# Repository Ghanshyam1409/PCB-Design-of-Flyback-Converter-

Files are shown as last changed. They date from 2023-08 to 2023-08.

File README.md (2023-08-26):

# PCB-Design-of-Closed- Loop-Flyback-Converter-
 PCB Design  of closed loop operation  Flyback Converter 
Flyback converter is DC-DC converter it is isolated converter we use transformer to boost the output voltage as compare to conventional DC-DC converter, Here we design the PCB for closed Loop opreation of Flyback Converter for controlling the output voltage of flyback converter we use type -II Compenstor topology

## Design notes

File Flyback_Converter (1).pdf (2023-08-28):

# Self Project

PCB Design of Clsoed Loop Control of Flyback Converter

Name : - GHANSHYAM DAS GUPTA Roll no . 224102109

## 1 Objective:

PCB Design of Flyback converter which is type of isolated converter, while we are using flyback converter as open loop configuration we will get the output voltage more than we required , so we use Type - II Compensator to regulate the output Voltage as per are requirement; Desired Gain Cross Over Frequency of Compensated System : 100Hz ; Desired Phase Margin : 120 degree

## 2 Given Parameter:

There are the parameter that we are going to use design of flyback converter

Input Voltage = 24 V , Duty Ratio= 0.33 , Capacitor = 220µF , Turn Ratio = 1 : 5 , Inductor = 22µH , Resistor = 5Ω , Inductor Resistance = 1Ω, D’=1 − 0.33 = 0.67,Switching Frequency = 10 KHz

## 3 Flyback Converter Design:

### 3.1 Derivation of Transfer function using small signal analysis:

The transfer function is derived using small signal analysis comes as:

Gvd(s) = Vo(s)
D(s)

=

Vin +

VO
n −

n∗VO
R∗D′ −

VO
R∗D′ ∗ (LS + D ∗ r)

n
D′ ∗

RCS+1
R

∗ (LS + D ∗ r) + D′
n

(1)

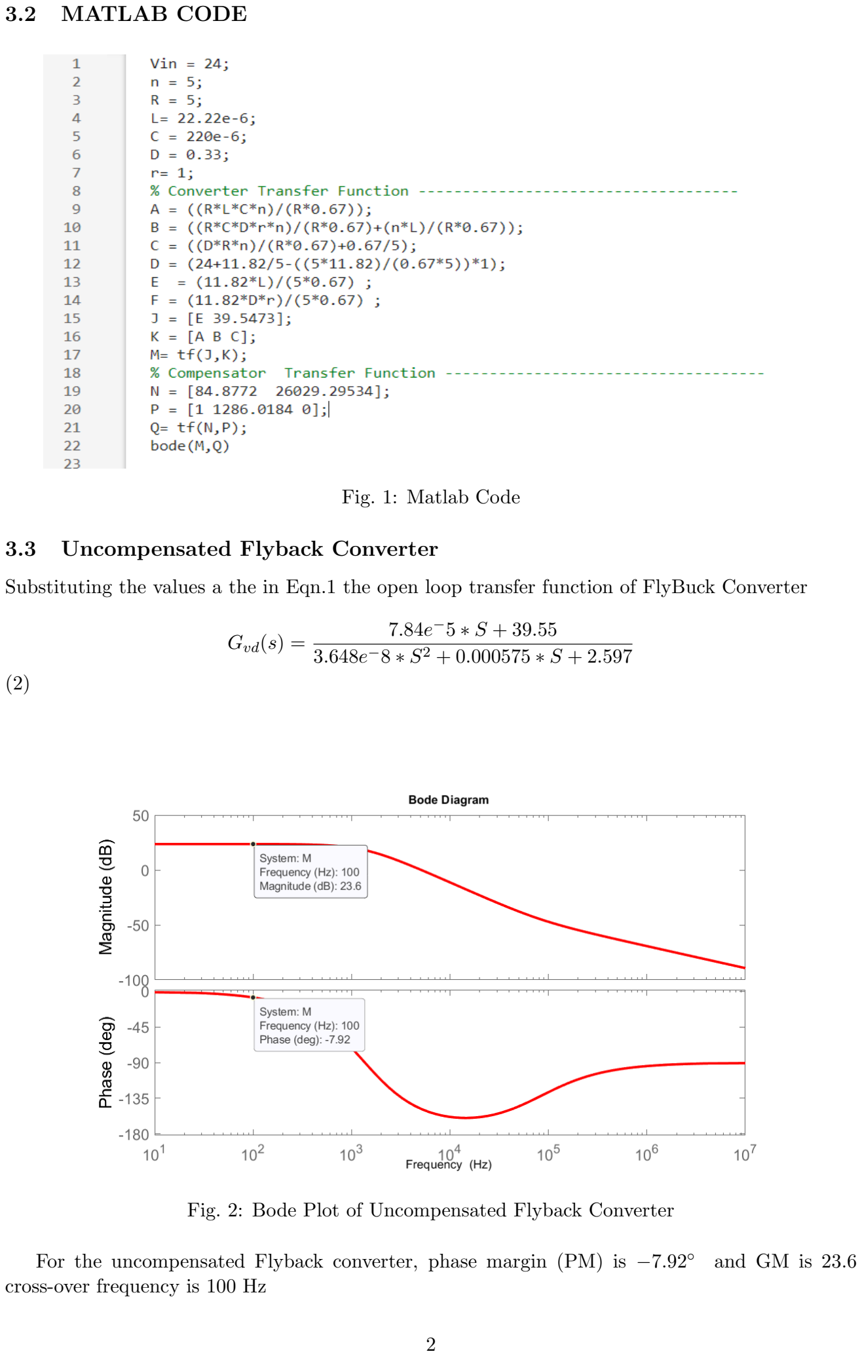
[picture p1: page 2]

### 3.2 MATLAB CODE

Fig. 1: Matlab Code

### 3.3 Uncompensated Flyback Converter

Substituting the values a the in Eqn.1 the open loop transfer function of FlyBuck Converter

Gvd(s) = | 7.84e

−5 ∗ S + 39.55
| 3.648e⁻8 ∗ S² + 0.000575 ∗ S + 2.597
(2)

Fig. 2: Bode Plot of Uncompensated Flyback Converter

For the uncompensated Flyback converter, phase margin (PM) is −7.92◦ and GM is 23.6 cross-over frequency is 100 Hz

### 3.4 Design of TYPE- II Compensator

- Since Desired the gain cross-over frequency 100 Hz. value of GMB is Given by

20 ∗ log 10K = 23.6

k = 15.1356

GMB =

1
K

= 0.0660

(3)

- Phase Margin (P.M.) is given 120◦
the phase margin of uncompensated Buck converter at Wgc is −7.94◦ by the help of this we can easily find the phase boost for that given system

ϕb = ϕm - ϕp -90◦
ϕb = 120◦ +0.907◦

-90◦
ϕb = 37.94◦

(4)

- Transfer Function of TYPE -II compensator is given by

a(s) = GMB ∗ (1 + ωz
s

)
(1 + s
ωp

)

(5)

k = tan(45◦ + ϕb/ 2)

k =1.732
ωz = (ωc)/k
ωp = (ωc)*k

On putting these two conditions, GMB = 0.0660 , ωz =306.670 rad/sec and ωp =1286.0184 rad/sec are obtained.

- The Transfer Function of TYPE- II Compensater is given by

a(s) = 84.8772 ∗ S + 26029.29534 S² + 1286.0184 ∗ S

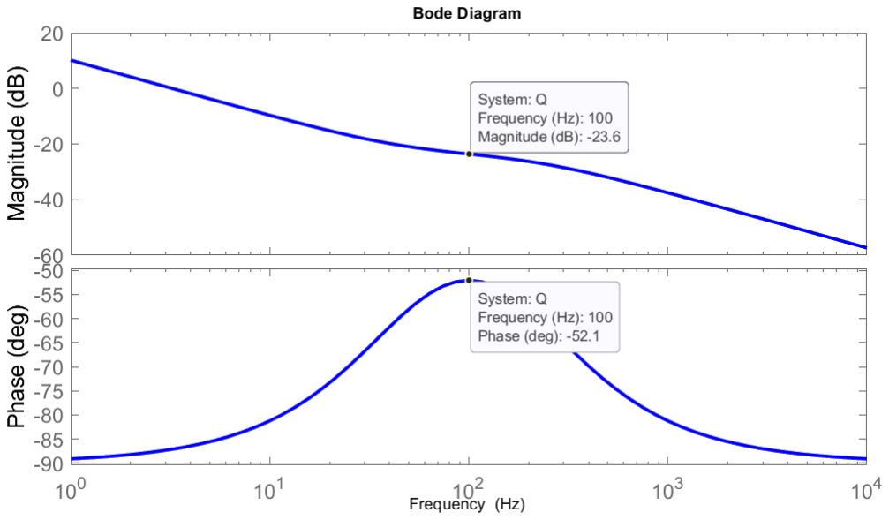
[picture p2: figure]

Fig. 3: Bode Plot of TYPE-II Compeansator

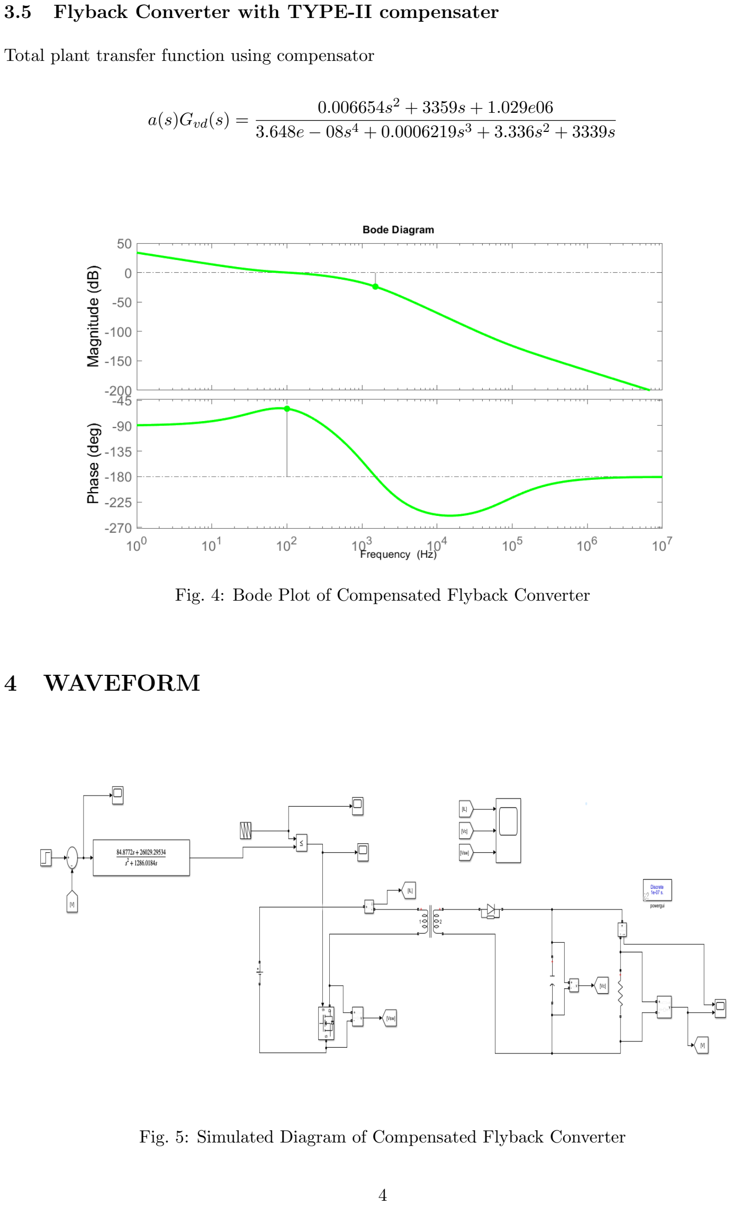
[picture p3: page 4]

### 3.5 Flyback Converter with TYPE-II compensater

Total plant transfer function using compensator

a(s)Gvd(s) = | 0.006654s

2 + 3359s + 1.029e06
| 3.648e − 08s 4 + 0.0006219s

3 + 3.336s

2 + 3339s

Fig. 4: Bode Plot of Compensated Flyback Converter

## 4 WAVEFORM

Fig. 5: Simulated Diagram of Compensated Flyback Converter

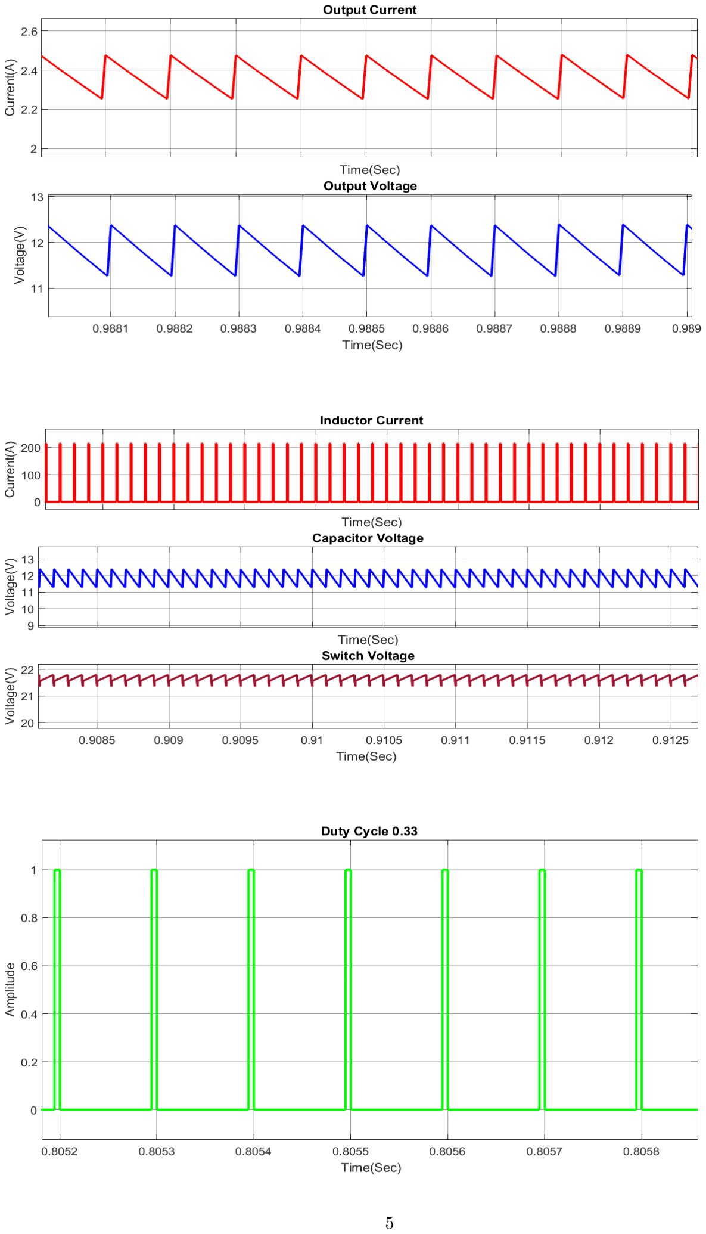
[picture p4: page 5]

## 5 LTspice Circuit Diagram

### 5.1 Triangular wave generator

Here we are generating triangular wave using op-amp and the switching frequency of MOSFET is 10 KHz whose peak to peak output voltage is 10 V , here we are considering resistance R1 =10Ω and capacitor c= 0.01µ F. Saturation voltage of op-amp is 15V

V (P − P) = 2 ∗

R2
R1

∗ Vsat

f =

R1
4 ∗ R3 ∗ R2 ∗ C1

### 5.2 Op-amp Subtractor

we design op-amp subs tractor to generate error and given it to the signal compansator then switching using gate driver. The output of the substractor must vary form 0 to 1, we take error value 0.5.so the calculted output value 11.82 and reference are given from the flyback output

Vo =

R2
R1

∗ (11.82 − Vout)

R1 = 0.0520K, R2 = 5.20K

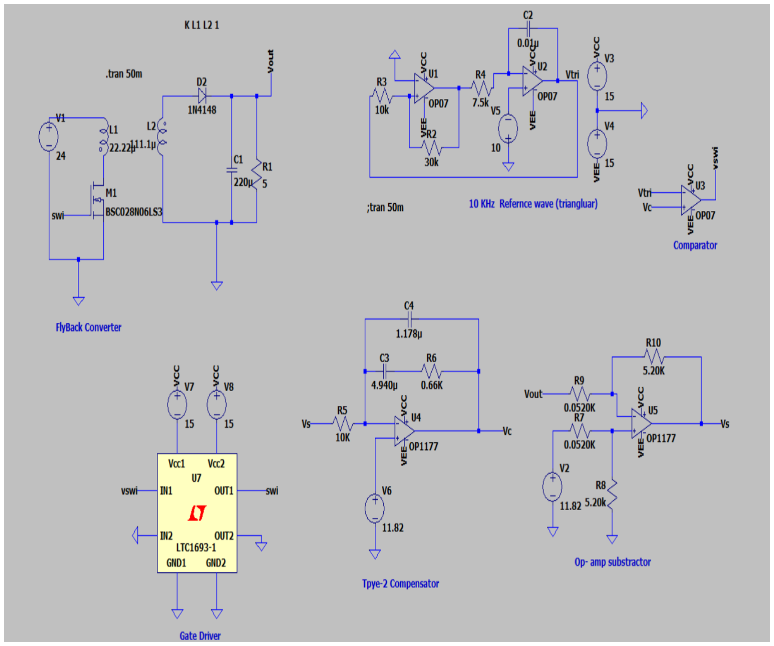
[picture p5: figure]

## 6 PCB module

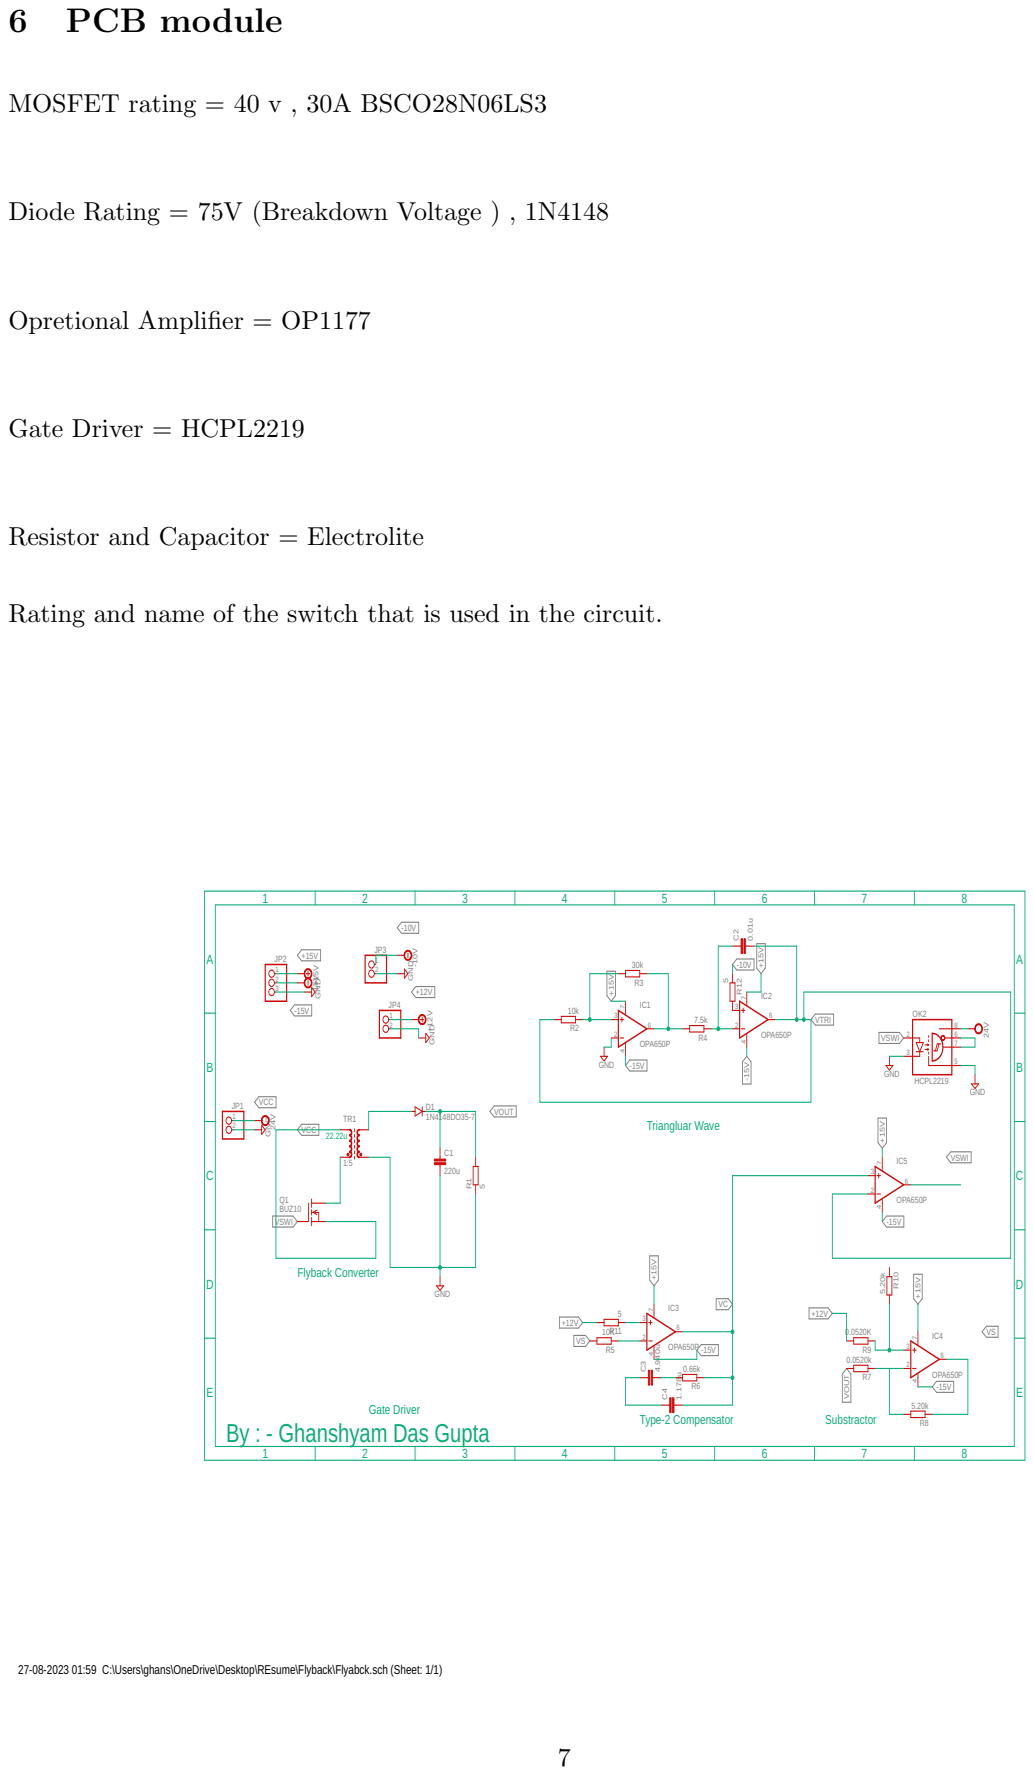
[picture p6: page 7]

Diode Rating = 75V (Breakdown Voltage ) , 1N4148

Resistor and Capacitor = Electrolite

Rating and name of the switch that is used in the circuit.

By : - Ghanshyam Das Gupta

27-08-2023 01:59 C:\Users\ghans\OneDrive\Desktop\REsume\Flyback\Flyabck.sch (Sheet: 1/1)

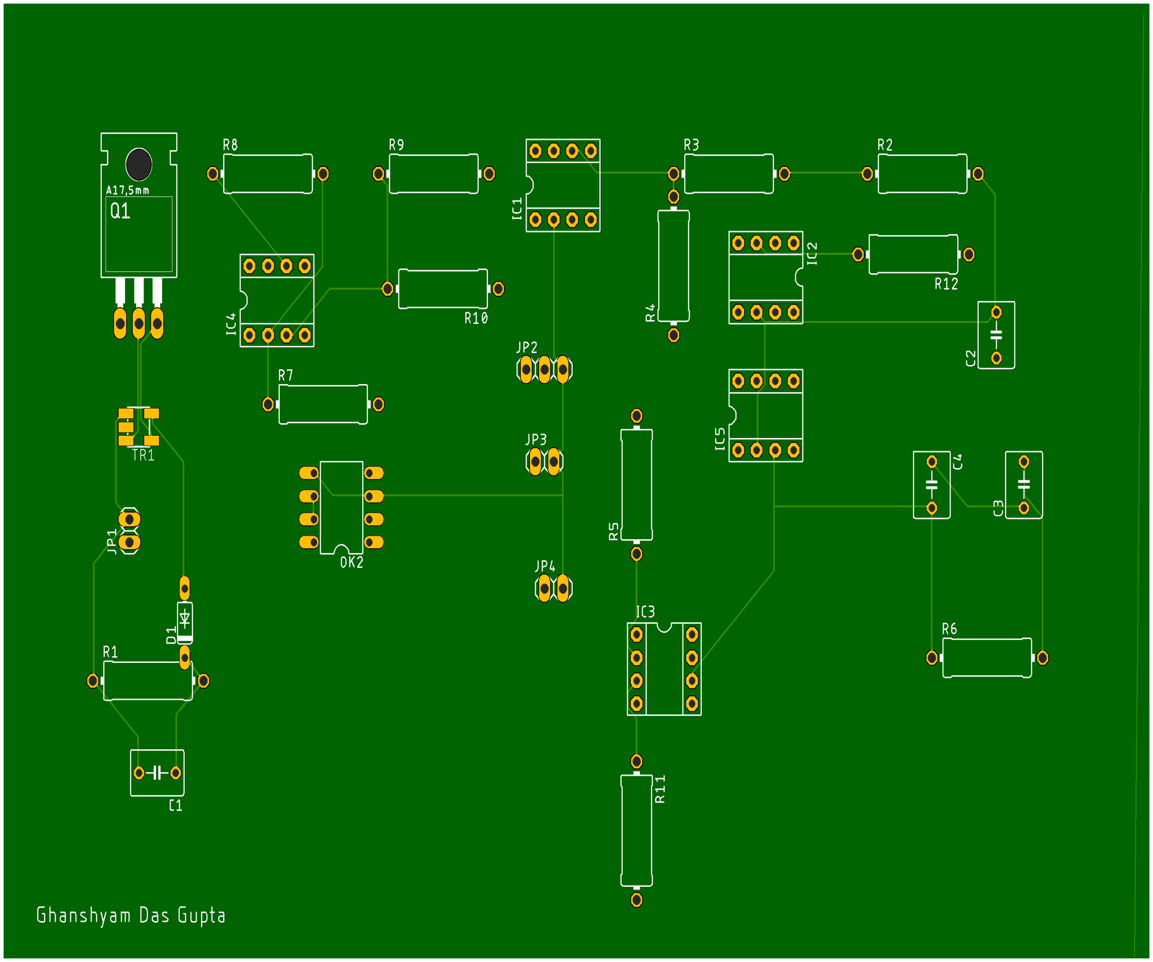
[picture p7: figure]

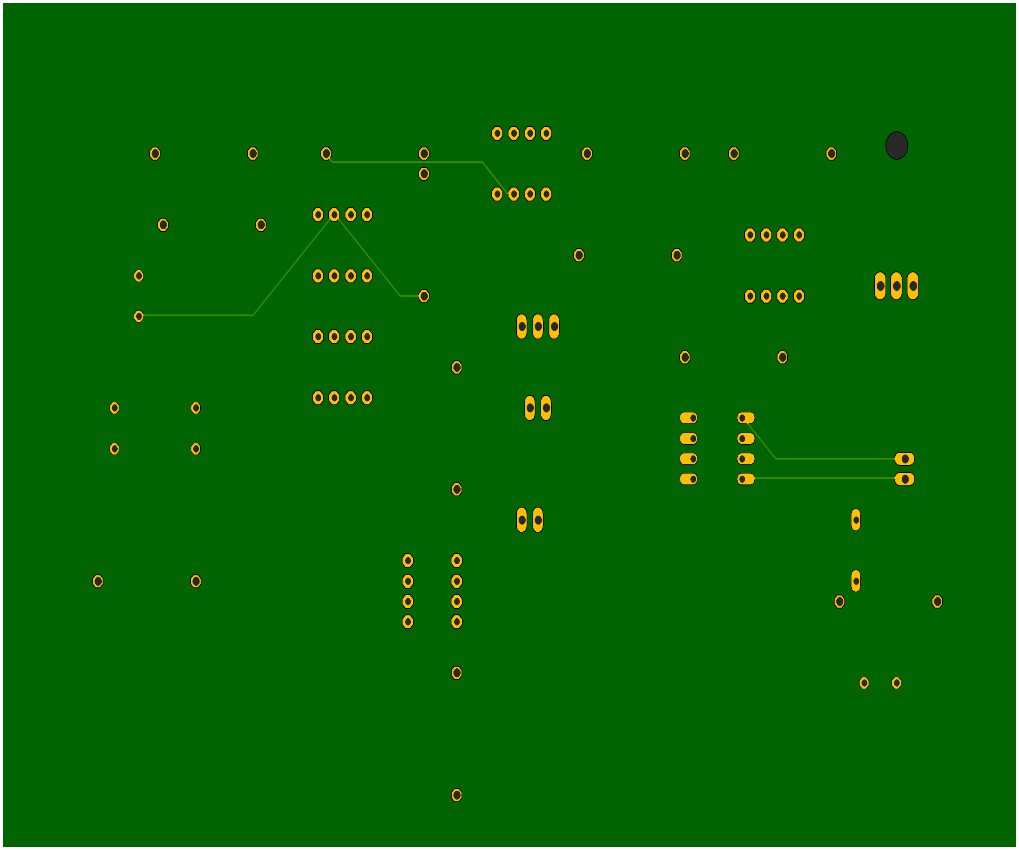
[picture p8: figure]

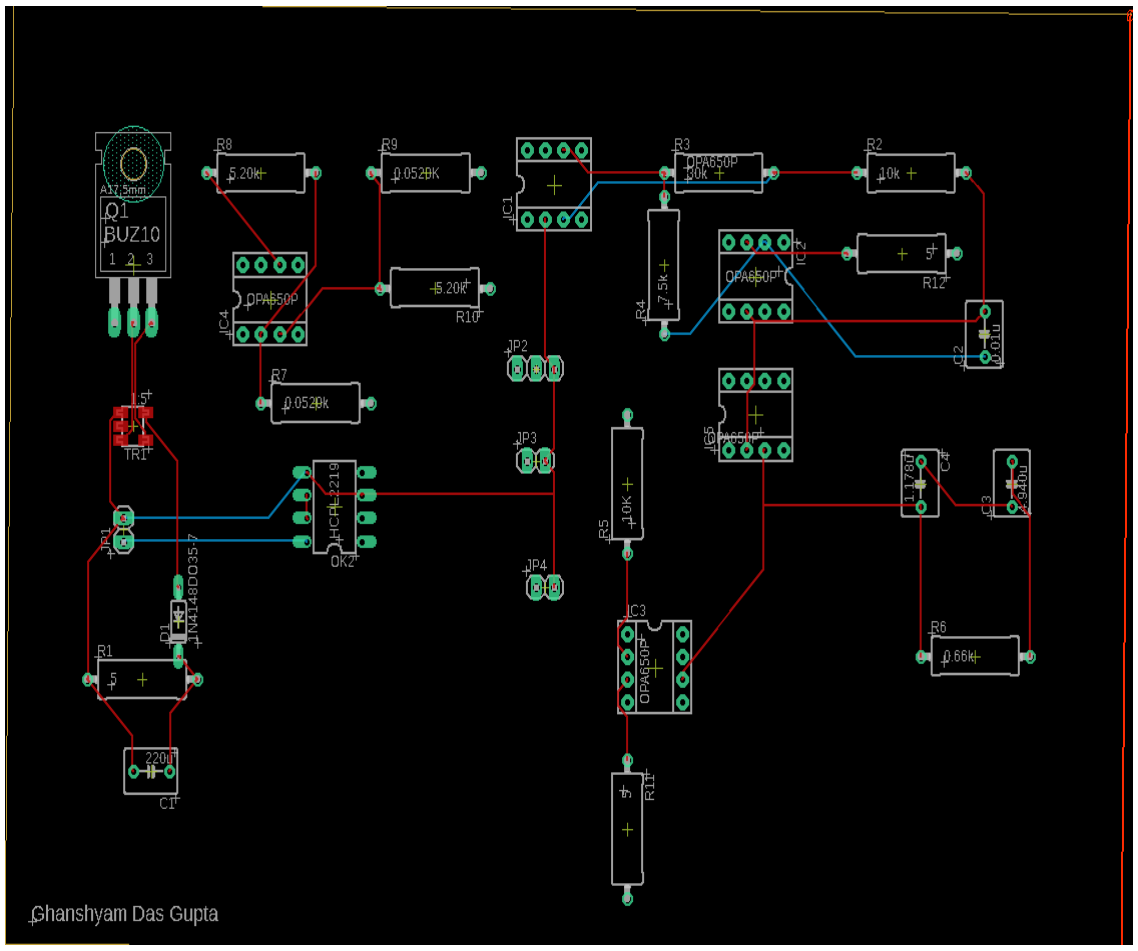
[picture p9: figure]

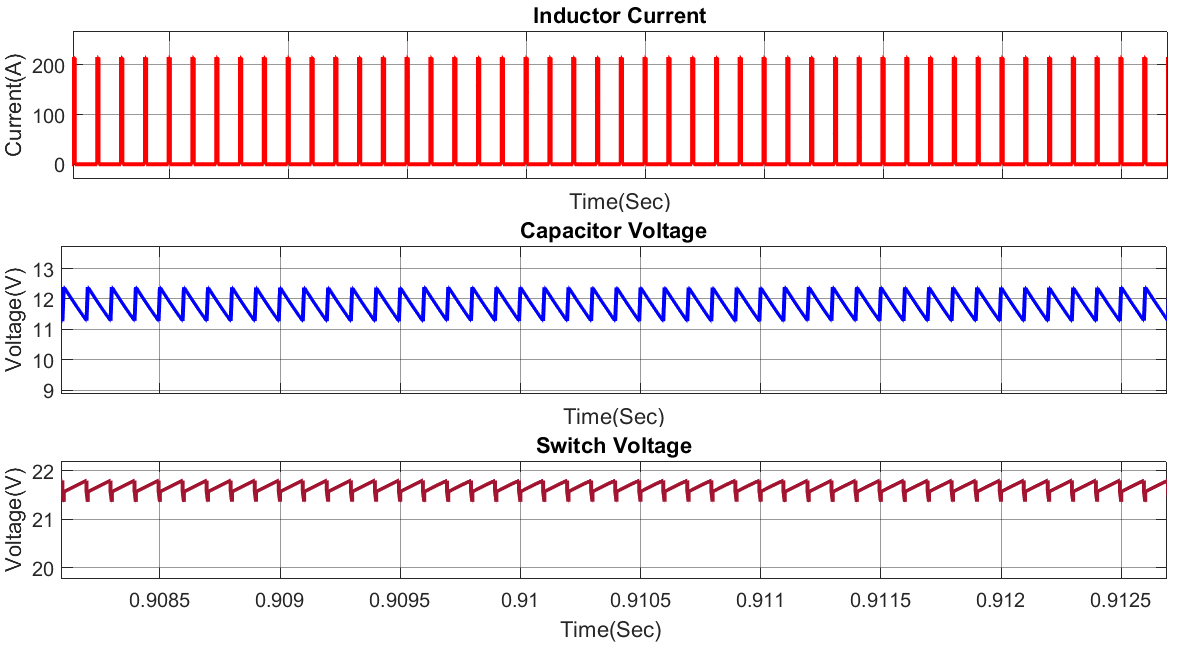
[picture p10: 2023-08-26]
swv.png

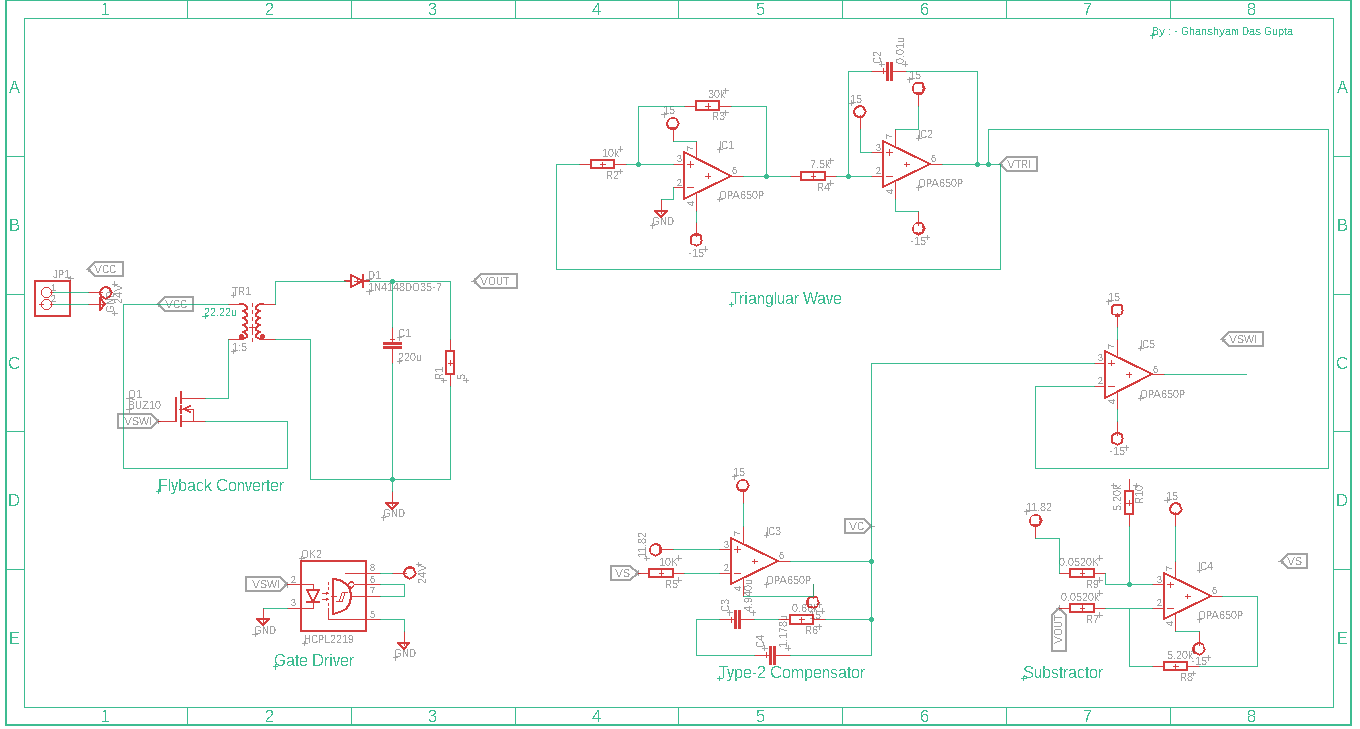
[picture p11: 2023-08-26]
pcb2.png

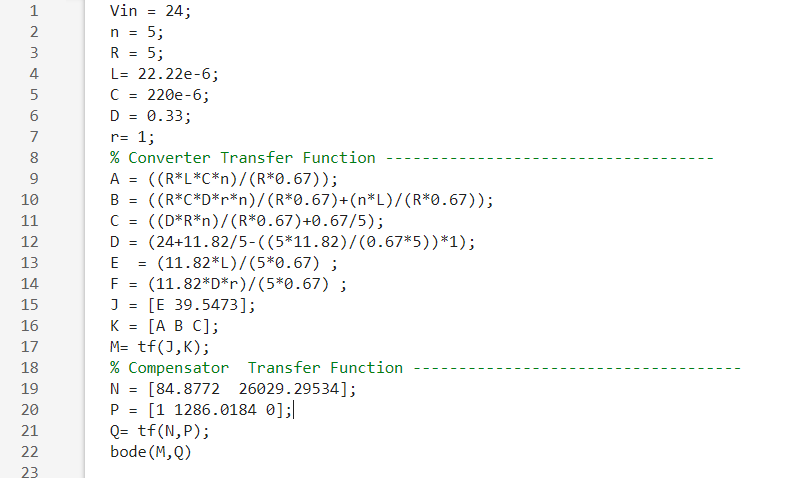
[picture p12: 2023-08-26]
tF.png

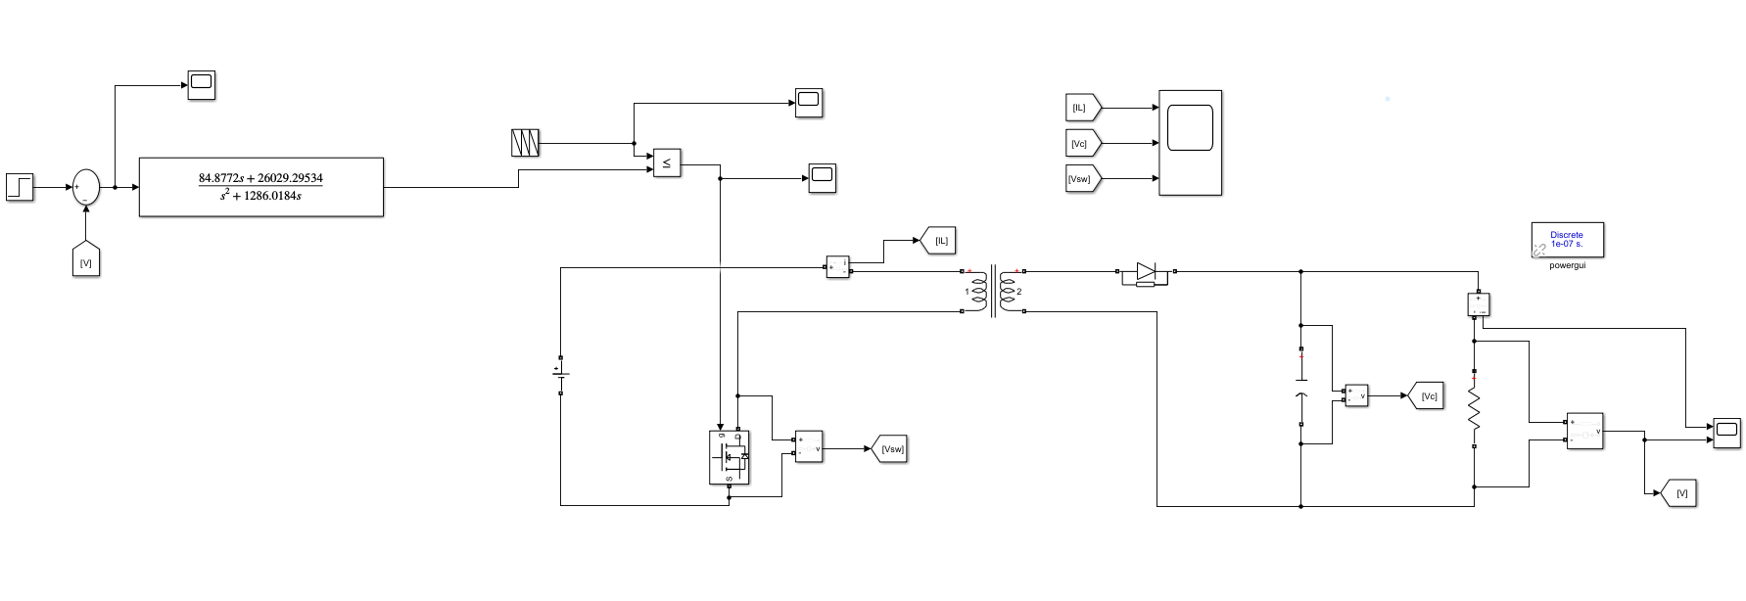
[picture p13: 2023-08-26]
simf.png

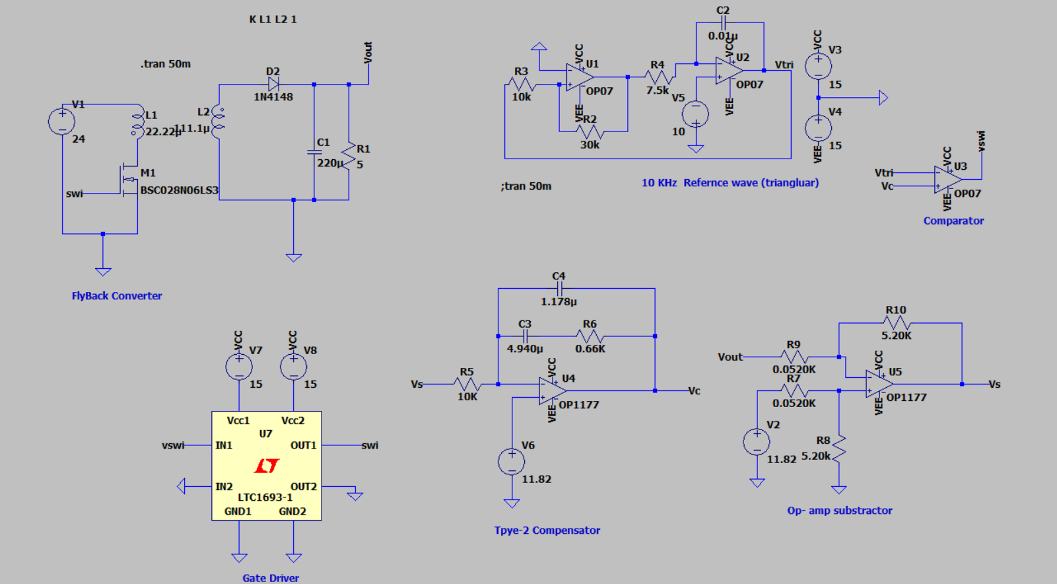
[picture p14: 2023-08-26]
LTspice.png

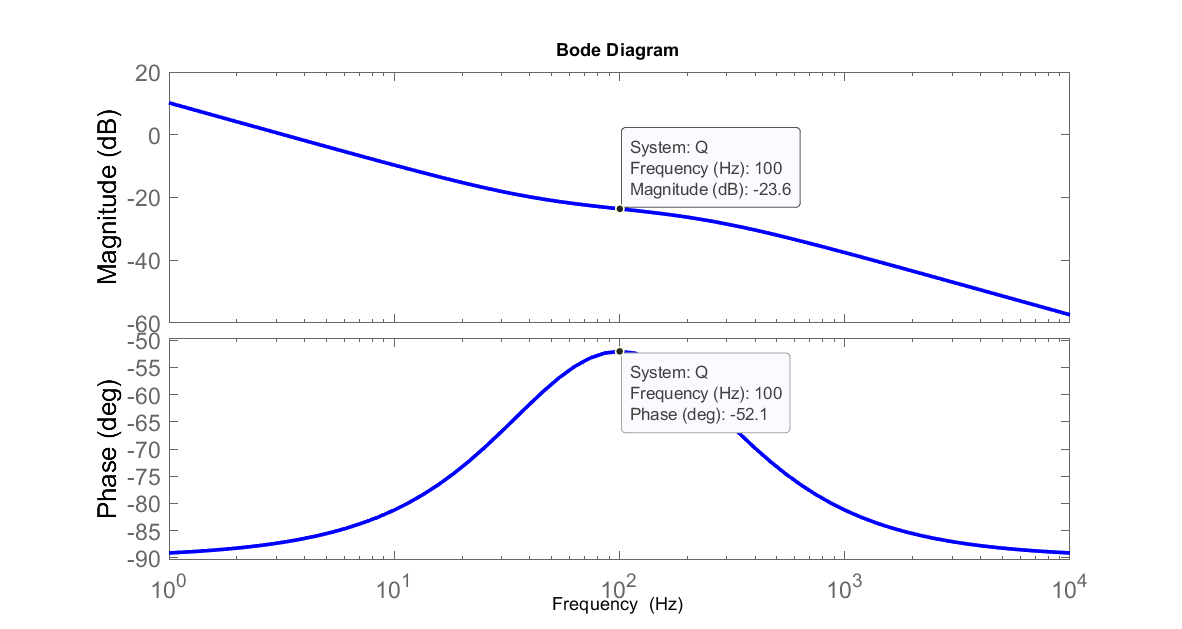
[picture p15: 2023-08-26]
Compen.png

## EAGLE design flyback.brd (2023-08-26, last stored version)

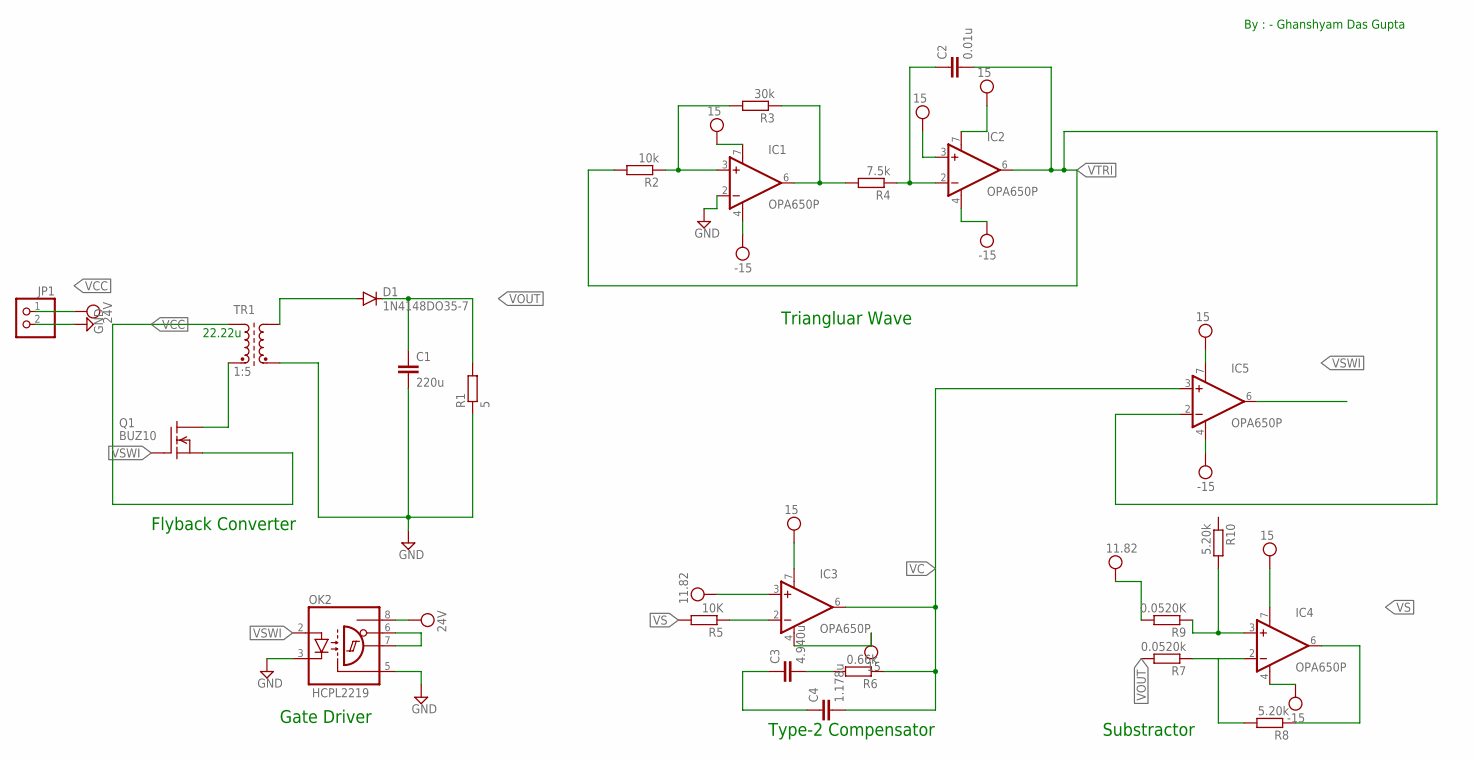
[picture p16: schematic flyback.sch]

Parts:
C1: 220u; C050-050X075
C2: 0.01u; C050-050X075
C3: 4.940u; C050-050X075
C4: 1.178u; C050-050X075
D1: 1N4148DO35-7; DO35-7
IC1, IC2, IC3, IC4, IC5: OPA650P; DIL08
JP1: PINHD-1X2; 1X02
OK2: HCPL2219; DIL08
Q1: BUZ10; TO220
R1: 5; 0414/15
R2: 10k; 0414/15
R3: 30k; 0414/15
R4: 7.5k; 0414/15
R5: 10K; 0414/15
R6: 0.66k; 0414/15
R7: 0.0520k; 0414/15
R8, R10: 5.20k; 0414/15
R9: 0.0520K; 0414/15
TR1: 1:5; SM-T4

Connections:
GND: C1.2, IC1.2 (-IN), JP1.2, OK2.3 (C), OK2.5 (GND), R1.1, TR1.4 (E2)
unnamed: Q1.3 (S), TR1.1 (A1)
unnamed: D1.A, TR1.5 (A2)
unnamed: IC1.3 (+IN), R2.1, R3.2
unnamed: OK2.6 (VE), OK2.7 (VO)
unnamed: Q1.2 (D), TR1.2 (E1)
unnamed: IC1.6 (OUT), R3.1, R4.2
unnamed: IC3.2 (-IN), R5.1
unnamed: C3.2, R6.2
unnamed: C2.1, IC2.2 (-IN), R4.1
unnamed: C3.1, C4.1
unnamed: IC4.3 (+IN), R9.1, R10.2
unnamed: IC4.2 (-IN), R7.1, R8.2
VC: C4.2, IC3.6 (OUT), IC5.3 (+IN), R6.1
VCC: IC1.4 (V-), IC1.7 (V+), IC2.3 (+IN), IC2.4 (V-), IC2.7 (V+), IC3.3 (+IN), IC3.4 (V-), IC3.7 (V+), IC4.4 (V-), IC4.7 (V+), IC5.4 (V-), IC5.7 (V+), JP1.1, OK2.8 (VCC), R9.2
VOUT: C1.1, D1.C, R1.2
VS: IC4.6 (OUT), R8.1
VSWI: IC5.6 (OUT)
VTRI: C2.2, IC2.6 (OUT), IC5.2 (-IN), R2.2

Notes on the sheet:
22.22u
By : - Ghanshyam Das Gupta
Flyback Converter
Triangluar Wave
Gate Driver
Type-2 Compensator
Substractor

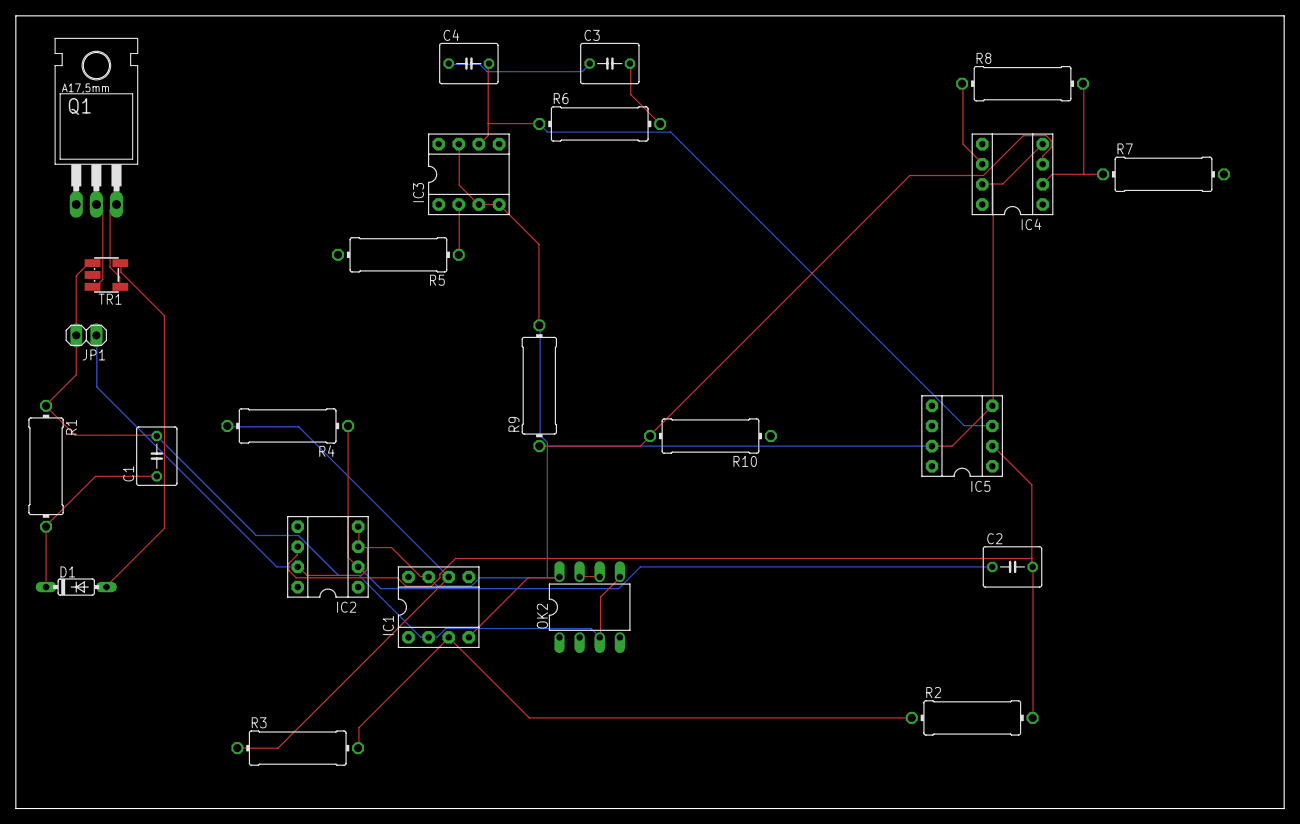
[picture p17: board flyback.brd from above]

Board: 2 copper layers, 160.0 x 100.0 mm, 24 parts (0 on the bottom side), 18 nets.
